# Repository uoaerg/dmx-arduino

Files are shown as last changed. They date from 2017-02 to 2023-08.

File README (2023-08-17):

This repository contains the full source code and hardware designs for the
Arduino shield used for teaching DMX at the University of Aberdeen. The Arduino
Mega 2560 compatible shield allows an Ardunio to operate as either a DMX bus
master or slave.

The dmx-arduino Board (Rev I and II) was designed by Cyril Danilesvski in 2014.
The software was written and was updated by Tom Jones, 2015-2017.
The software is updated by Gorry Fairhurst, 2020-2023.

# Uploading the code

Open the Arduino project from dmxcontroller/dmxcontroller.ino.

Import the libraries from the libraries/ into the Arduino IDE. It is
important that you do not allow the Aruduino IDE to update these libraries.

Compile and upload.

# Operation

Program mode and DMX addressing are controlled by the 12 dip switches on the
main sheild PCB. Program status is indicated using the three LEDs in most
program modes or using additional LEDs on the DE9 connector in other modes.

There is a default program that can is used in any empty slot in the program
mode. This program will only blink the green LED.

The RED LED on the board provides the DMX status. If valid DMX data has been seen
on the bus, then DMXTIMEOUT will flash the red LED. If no valid DMX data has
been seen for 1 sec this LED will be lit solidly. This functionality operates 
outside the control of any of the programs.

When the main loop of the program detects a change in program mode the green
LED will be flashed momentarily. This flash can be difficult to see when
turning off DIP switches, but is easier to see when turning on DIP switches.

## DIP Switches

The 12 DIP switches form a 12-bit number with the MSB starting with switch 1.
The program mode is encoded in the top three bits of the DIP switches and the
DMX address is encoded in the bottom 9 bits.

                  1 1 1
1 2 3 4 5 6 7 8 9 0 1 2
P P P D D D D D D D D D

The software has 8 modes (3 bits):

0 - DMX Controller
1 - Digital Output Control
2 - PWM Control 
3 - Servo Control
4 - Neopixel Strip Control
5 - Stepper Motor Control
6 - Unused.
7 - Long Strip Control

0 - DMX Controller Mode
	The programmed DMX address will be displayed on the 8 DE2PINs with the 9th
	bit displayed on the green LED.

	If a DMX address of 0 is selected on the DIP switches, the slot sequence
	0x55 0xFF 0x0F 0xF0 will be output for the first four DMX slots.

	In controller mode, the program will read from a 10K pot connected to POT_PIN. The
	10bit value from the ADC will be scaled (divided by 4) to fit with in a DMX
	byte. If this value is greater than 128, then the yellow LED will be lit. The
	scaled value from the pot. will be written to the DMX bus at the slot set by the DMX
	address.

1 - Digital control
	Eight DMX channels will be read from the bus. If the DMX value is
	greater than 128, then the corresponding DE2PIN will set high.

	The yellow LED shows the status of channel 1.

2 - PWM Control 
	The first eight DMX channels will be read from the bus. The corresponding
	DE2PINs will be given a PWM values from the DMX value.

	The yellow LED shows the status of channel 1.

3 - Servo Control
	The servo will be driven to a position based upon the DMX value at the selected
	DMX address.

	The yellow LED shows the status of channel 1.

4 - Neopixel Control
	An encoded colour value will be read from a set of DMX slots. Each *byte*
	encodes an RGB value. These values are split out then set to an attached
	LED strip using the Neopixel Library. These are sent as a time division
	multiplex as 3 serialised 8-bit colour values using the assigned pin.

	The yellow LED shows the status of channel 1.

5 - Stepper Motor Control
	An encoded stepper motor control value will be read from a set of DMX slots. 
	A set of 2 slots control the speed of rotation of the stepper motor and direction.
	A set of 2 slots sets an index position, and then controls the relative angle to 
	the indexed position. The rotation controls also control the speed of movement.

7 - Long Neopixel Control
	As mode 5, but with the timing adjusted to allow a long strip to be driven.

	The yellow LED shows the status of channel 1.

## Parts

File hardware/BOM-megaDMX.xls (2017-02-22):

Id | Designator | Description | Quantity | Designation | Supplier | Reference | Unit Price
1 | R2,R1 | Opto-couplers resistors | 2 | 330 | CPC | 2329531 | £0.004
2 | SHIELD1 | Arduino Mega shield | 1 | ARDUINO_MEGA_SHIELD | Pcb-Train |  | £6.34
3 | IC1 | Line Driver | 1 | 75176 | CPC | SC08420 | £0.20
4 | U1,U2,U3 | Opto-couplers | 3 | 6N137 | CPC | SC08395 | £0.85 | RS STOCK
5 | C1,C4,C2,C5,C3 | Integrated Circuits capacitors | 5 | 100nF | CPC | CA06294
6 | R10,R8 | DMX-RDM resistors | 2 | 562 | CPC | 1563234 | £0.004
7 | R9 | DMX-RDM resistors | 1 | 133 | Farnell | 9464417 | £0.004
8 | R6,R4,R5,R3 | Opto-couplers resistors | 4 | 470 | Farnell | 2329531 | £0.004
9 | J1 | DE9MD | 1 | J1 | CPC | 1260035 | £0.29
10 | K1 | 3 pin terminal block for XLR | 1 | XLR3 | CPC | 2008016 | £0.88
11 | IC2 | 5v DC-DC converter | 1 | NME5050SC | CPC | 1021456 | £3.41
12 | L1 | DC-DC inductor | 1 | 47uH | CPC | 2062675 | £0.24
13 | U4 | Octal buffer | 1 | 74HTC240 | CPC | SC09024 | £0.13 | RS STOCK
15 | C6 | DC-DC capacitor - CAP, ALU ELEC, 4.7UF | 1 | 47uF | CPC | 1236689 | £0.06
16 | C7 | C1 | 1 | 10nF | CPC | 2309024 | £0.02
17 | R11,R12,R13 | LED resistor | 3 | 220 | CPC | 2329500 | £0.01
18 | D2 | LED 3MM | 1 | LED | CPC | 2112096 | £0.12
19 | D3 | LED 3MM | 1 | LED | CPC | 2112104 | £0.12
20 | D4 | LED 3MM | 1 | LED | CPC | 2112106 | £0.12
21 | P1,P2,P3,P4 | Headers: serial & scope | 1 | RX_JMP,TX_JMP,RX,TX | CPC | 5217805 | £3.09
22 | SW1 | DIP switches 12 | 1 | DIPS | CPC | 1530701 | £1.42
24 | n/a | Double row long legged headers | 2 | Pin 22 through 53 | CPC | 1769164 | £2.70 | NO STOCK
25 | n/a | Stackable header kit | 1 | All other pins | CPC | SC12964 | £1.59
26 | n/a | LCD display | 1 |  | CPC | SC12121 | £4.28
27 | n/a | Arduino Mega | 1 |  | CPC | 1848688 | £15.00
28 | n/a | DIP SOCKET 20 | 1 |  | Farnell | 1183577 | £0.12
 |  |  |  |  | No arduino Total |  | £25.99
 |  |  |  |  |  | TOTAL | £40.99

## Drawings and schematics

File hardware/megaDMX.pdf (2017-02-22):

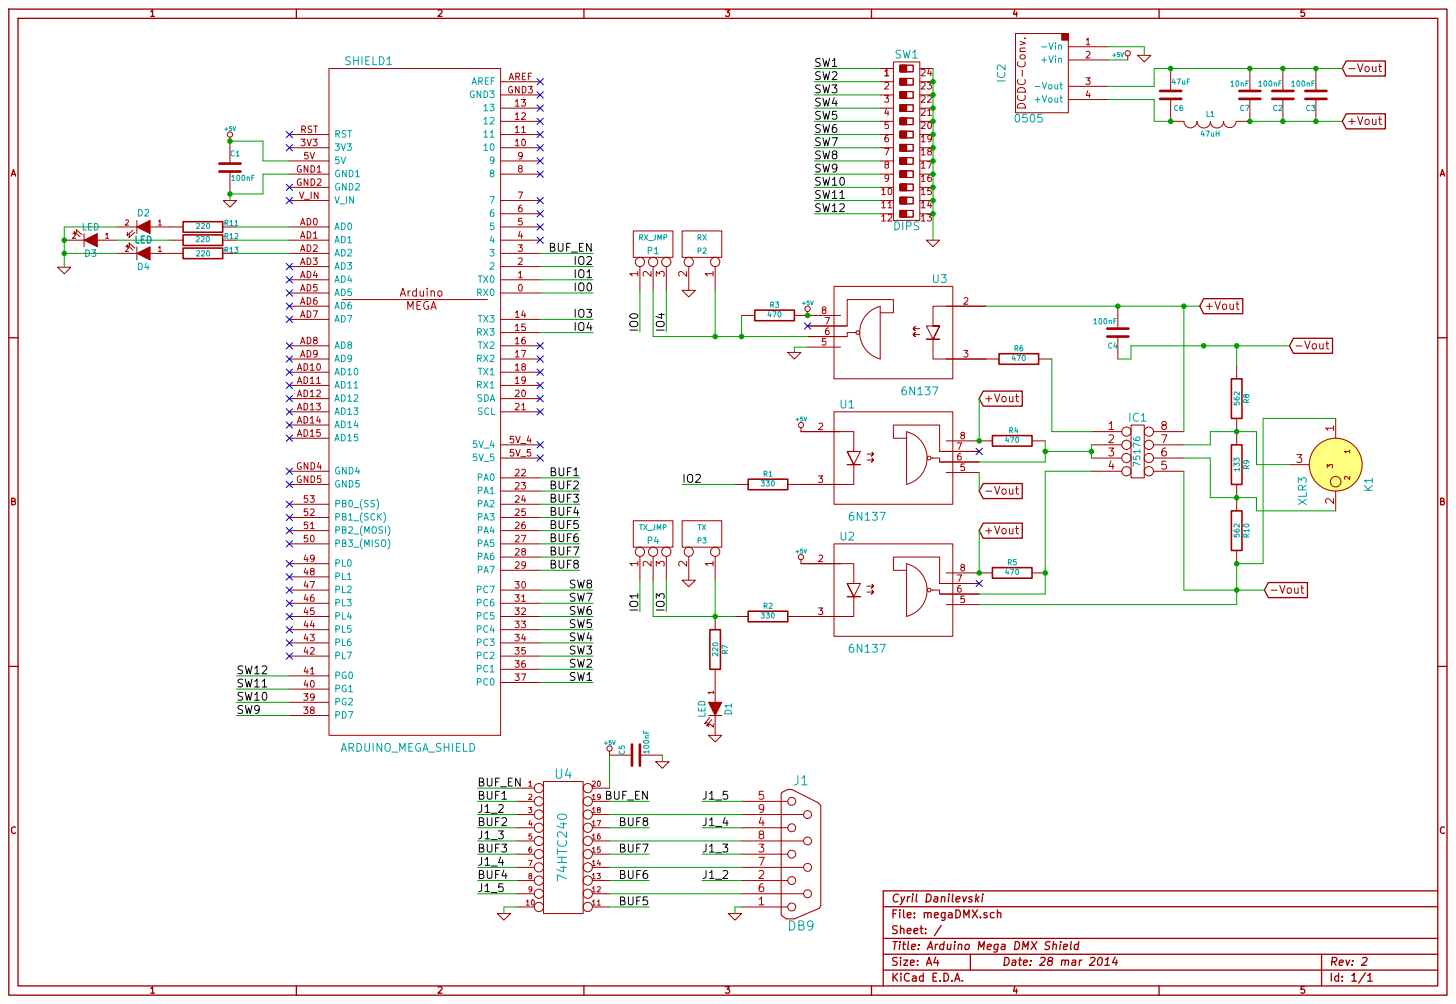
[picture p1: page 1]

File: megaDMX.sch
Sheet: /
Title: Arduino Mega DMX Shield

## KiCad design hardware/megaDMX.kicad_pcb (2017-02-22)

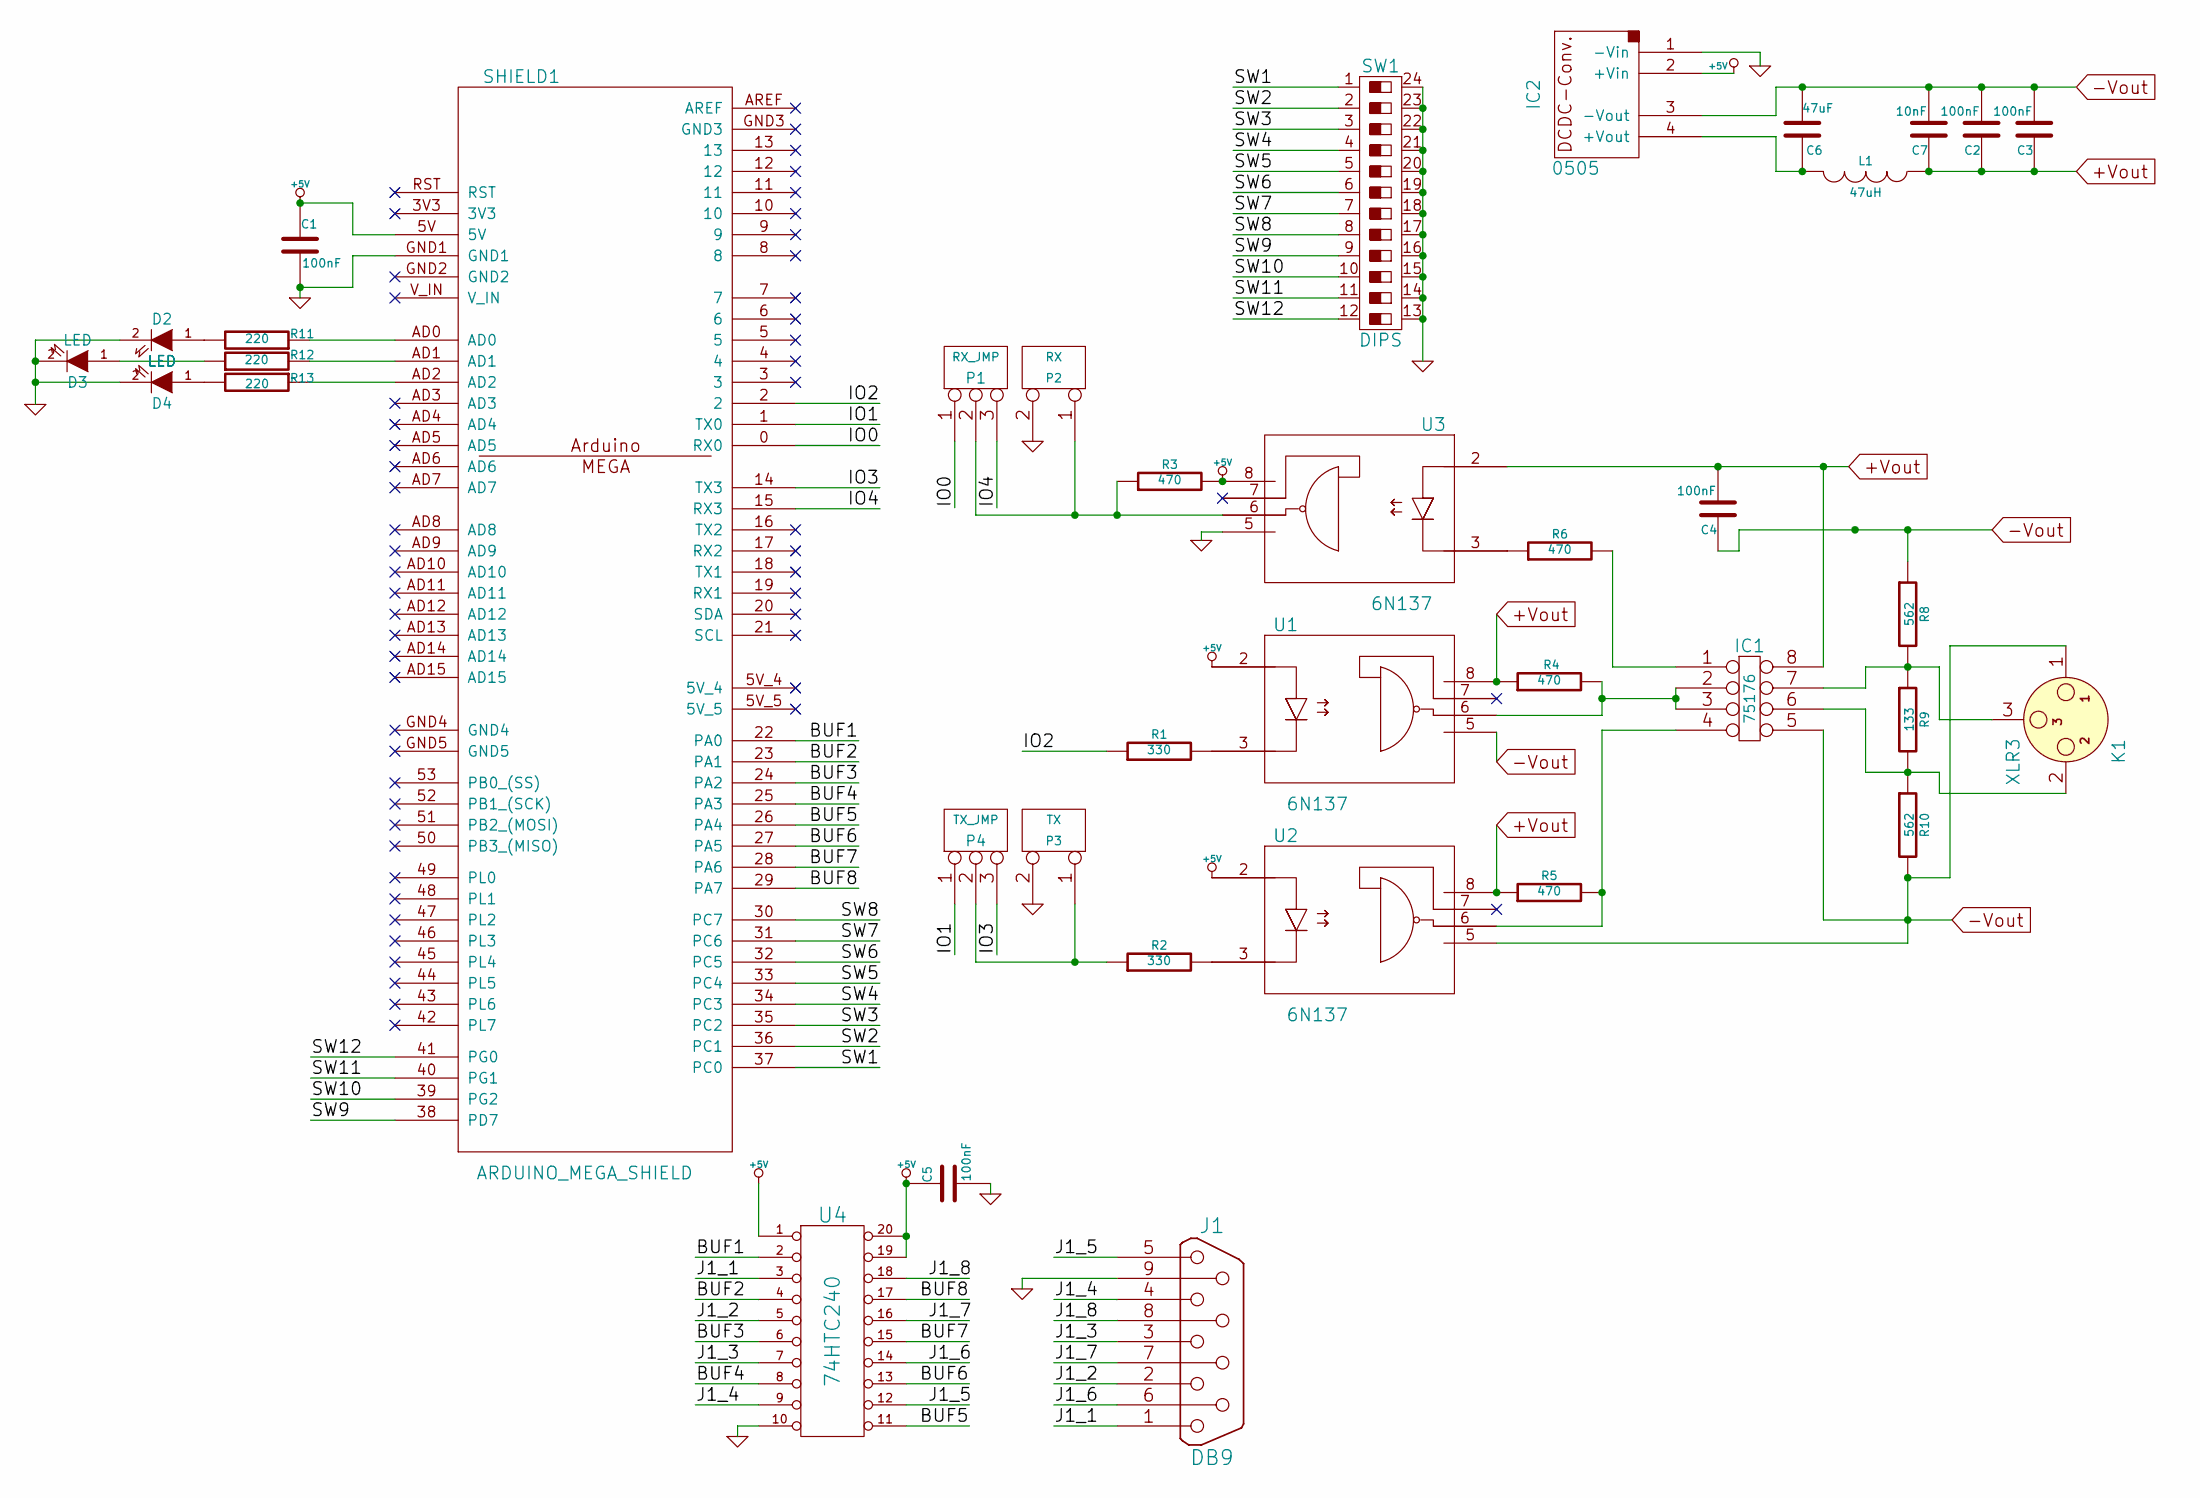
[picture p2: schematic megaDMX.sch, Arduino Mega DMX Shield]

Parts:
C1, C2, C3, C4, C5: 100nF
C6: 47uF
C7: 10nF
D2, D3, D4: LED
IC1: 75176
IC2: 0505
J1: DB9
K1: XLR3
L1: 47uH
P1: RX_JMP
P2: RX
P3: TX
P4: TX_JMP
R1, R2: 330
R3, R4, R5, R6: 470
R8, R10: 562
R9: 133
R11, R12, R13: 220
SHIELD1: ARDUINO_MEGA_SHIELD
SW1: DIPS
U1, U2, U3: 6N137
U4: 74HTC240

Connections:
+5V: C1.1, C5.1, IC2.2 (+Vin), R3.2, SHIELD1.5V, U1.2, U2.2, U3.8, U4.1, U4.19, U4.20
+Vout: C2.1, C3.1, C4.2, C7.1, IC1.8, L1.1, R4.1, R5.1, U1.8, U2.8, U3.2
-Vout: C2.2, C3.2, C4.1, C6.2, C7.2, IC1.5, IC2.3 (-Vout), K1.1, R8.1, R10.2, U1.5, U2.5
/BUF1: SHIELD1.22 (PA0), U4.2
/BUF2: SHIELD1.23 (PA1), U4.4
/BUF3: SHIELD1.24 (PA2), U4.6
/BUF4: SHIELD1.25 (PA3), U4.8
/BUF5: SHIELD1.26 (PA4), U4.11
/BUF6: SHIELD1.27 (PA5), U4.13
/BUF7: SHIELD1.28 (PA6), U4.15
/BUF8: SHIELD1.29 (PA7), U4.17
/IO0: P1.1, SHIELD1.0 (RX0)
/IO1: P4.1, SHIELD1.1 (TX0)
/IO2: R1.1, SHIELD1.2
/IO3: P4.3, SHIELD1.14 (TX3)
/IO4: P1.3, SHIELD1.15 (RX3)
/J1_1: J1.1, U4.3
/J1_2: J1.2, U4.5
/J1_3: J1.3, U4.7
/J1_4: J1.4, U4.9
/J1_5: J1.5, U4.12
/J1_6: J1.6, U4.14
/J1_7: J1.7, U4.16
/J1_8: J1.8, U4.18
/SW1: SHIELD1.37 (PC0), SW1.1
/SW2: SHIELD1.36 (PC1), SW1.2
/SW3: SHIELD1.35 (PC2), SW1.3
/SW4: SHIELD1.34 (PC3), SW1.4
/SW5: SHIELD1.33 (PC4), SW1.5
/SW6: SHIELD1.32 (PC5), SW1.6
/SW7: SHIELD1.31 (PC6), SW1.7
/SW8: SHIELD1.30 (PC7), SW1.8
/SW9: SHIELD1.38 (PD7), SW1.9
/SW10: SHIELD1.39 (PG2), SW1.10
/SW11: SHIELD1.40 (PG1), SW1.11
/SW12: SHIELD1.41 (PG0), SW1.12
GND: C1.2, C5.2, D2.2 (K), D3.2 (K), D4.2 (K), IC2.1 (-Vin), J1.9, P2.2 (PM), P3.2 (PM), SHIELD1.GND1, SW1.13, SW1.14, SW1.15, SW1.16, SW1.17, SW1.18, SW1.19, SW1.20, SW1.21, SW1.22, SW1.23, SW1.24, U3.5, U4.10
unnamed: R11.1, SHIELD1.AD0
unnamed: D2.1 (A), R11.2
unnamed: D4.1 (A), R13.2
unnamed: D3.1 (A), R12.1
unnamed: R12.2, SHIELD1.AD1
unnamed: R13.1, SHIELD1.AD2
unnamed: C6.1, IC2.4 (+Vout), L1.2
unnamed: P3.1, P4.2 (PM), R2.1
unnamed: P1.2 (PM), P2.1, R3.1, U3.6
unnamed: IC1.1, R6.2
unnamed: IC1.2, IC1.3, R4.2, U1.6
unnamed: IC1.6, K1.2, R9.2, R10.1
unnamed: IC1.7, K1.3, R8.2, R9.1
unnamed: R6.1, U3.3
unnamed: IC1.4, R5.2, U2.6
unnamed: R2.2, U2.3
unnamed: R1.2, U1.3

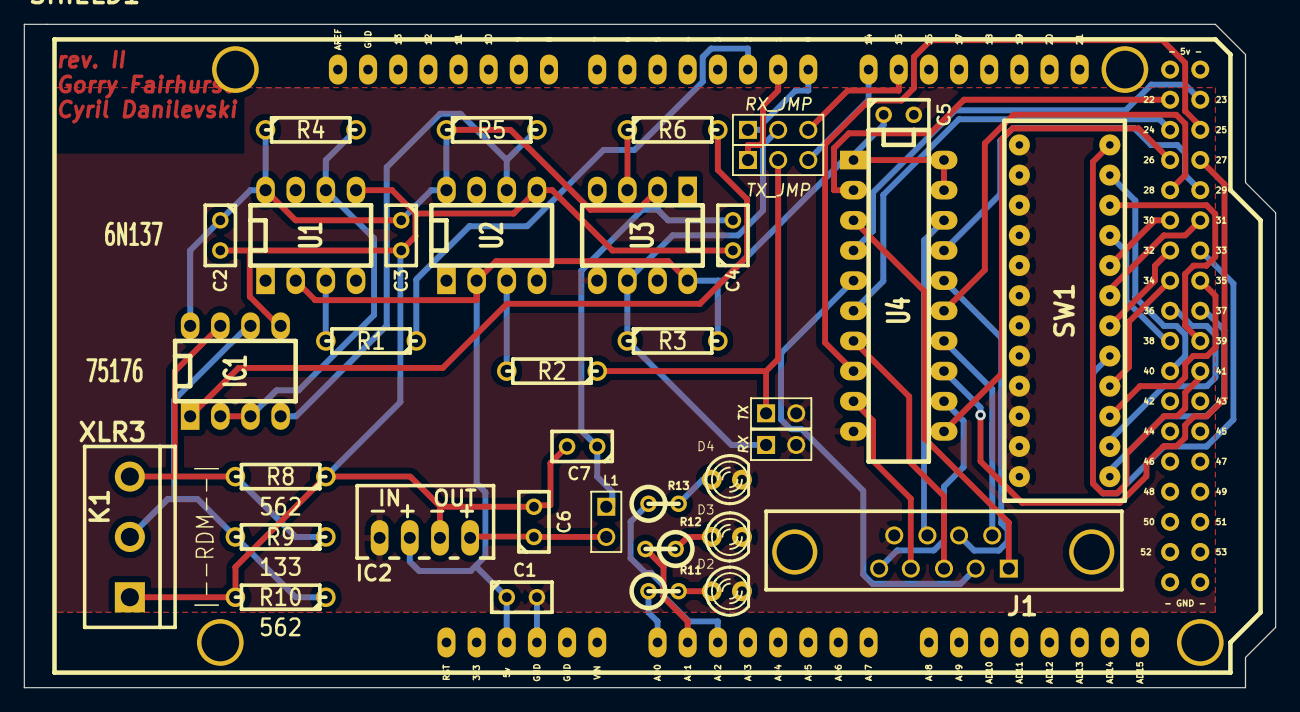
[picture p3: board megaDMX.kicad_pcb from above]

Board: 2 copper layers, 105.4 x 55.9 mm, 37 parts (0 on the bottom side), 54 nets.

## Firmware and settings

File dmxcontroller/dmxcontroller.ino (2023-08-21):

#include <DMXSerial.h>

/* dmx controller */
/*
 * Copyright (c) 2017 Tom Jones, UoA tom@erg.abdn.ac.uk
 * Copyright (c) 2023 Gorry Fairhurst, UoA gorry@erg.abdn.ac.uk
 * All rights reserved.
 *
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
 */

/* Rewrite completed by Aug 2023 */


/* NOTE USE INCLUDED LIBRARYIES ONLY,
A SERIAL CONFLICT exists in the on-line library,
https://github.com/mathertel/DMXSerial/tree/master
The Arduino MEGA 2560 boards use the serial port 0 on pins 0 an 1.
The vector numbers differ because you use the Mega board and not the UNO.
On Mega you have the option to use the port 1 for DMX and the Serial for printing to the Monitor.
see https://github.com/mathertel/DMXSerial/blob/master/src/DMXSerial_avr.h 
for details to enable DMX_USE_PORT1 and change your wiring.
The hack here is to reload DMX after each pixel load.
Aug 2023 GF */

#include <DMXSerial.h>
#include <Servo.h>

#include <Adafruit_NeoPixel.h>

extern "C" {
  #include "dmxboard.h"
  #include "pins.h"
  #include "dip.h"
}

#define DMXADDRESSMAX 513   /* maximum number of channels read in a frame */

/* Libary does not eturn DMXTIMEOUT correctly */
#define DMXTIMEOUT 1000   /* One Second timeout to take receiver off-line */

void controllermain(void);
void digitalmain(void);
void pwmmain(void);
void servomain(void);
void neopixelmain(void);
void steppermain(void);
void defaultprogram(void);
void neopixellong(void);
void printdipmode(void);

void readDMXChannels(int *, uint16_t );
void readStartDMXChannels(int *, uint16_t, uint16_t startaddr );

void stepmotor(int *motorpins, int *motorsteps, int direction, int step);
void stopmotor(int *motorpins);

int OutputDisabled;   /* Disable output signal */
uint8_t readRed(uint8_t);
uint8_t readGreen(uint8_t);
uint8_t readBlue(uint8_t);

void (*program)(void);
Servo servos[SERVOPINS_MAX];
int16_t indexposition = 0;

/* Driver for the WS2812 3-colour LED strip */
/* each pixel is programmed in a chain with 3x 8-bit colour values */
Adafruit_NeoPixel strip = Adafruit_NeoPixel
(
  LONGLEDCOUNT,   /* Maximum number of LEDs on the strip - use the longest size */
  STRIP_PIN,    /* Arduino output pin used for control */
  NEO_GRB + NEO_KHZ800  /* Colour Byte order and Strip Speed */
);

/* This is the menu for the switch configuration */
#define NUMPROGRAMS 8
void (*programs[NUMPROGRAMS])(void) = {
  controllermain,   /* Mode 0 */
  digitalmain,  /* Mode 1 */
  pwmmain,  /* Mode 2 */
  servomain,  /* Mode 3 */
  neopixelmain, /* Mode 4 */
  steppermain,  /* Mode 5 */
  defaultprogram, /* Mode 6 */
  neopixellong, /* Mode 7 */
};

/* This is the menu as a list of programs */
/* Note lsb and msb versions of the mode are provided in the comments ! */
char *program_name[]= {
  "DMX Controller ",  /* Mode 0  000 msb: 000 */
  "Digital Control",  /* Mode 1  001 msb: 100 */
  "PWM Control    ",  /* Mode 2  010 msb: 010*/
  "Servo Control  ",  /* Mode 3  011 msb: 110 */
  "Pixel Control  ",  /* Mode 4  100 msb: 001 */
  "Stepper Control",  /* Mode 5  101 msb: 101*/
  " --- None ---  ",  /* Mode 6  110 msb: 011 */
  "Long Pixel Cont.", /* Mode 7  111 msb: 111 */
};

/* -------------------------------------------------------------------------- */


void setup(void)
{

  /* Configure pins */
  pinMode(GREEN_LED, OUTPUT);
  pinMode(YELLOW_LED, OUTPUT);

  /* RED status LED on board
   * RED On indicates no DMX data; RED flashing indicates good DMX frames received. */
  pinMode(RED_LED, OUTPUT);

  pinMode(STRIP_PIN, OUTPUT);

  pinMode(POT_PIN, INPUT);
  pinMode(POT_PIN2, INPUT); // GF
  pinMode(POT_PIN3, INPUT); // GF
  pinMode(POT_PIN4, INPUT); // Gf
  pinMode(SENS_PIN5, INPUT); // GF - sensor input

  /* DIP switch input of address and mode */
  for(int i = 0; i < DIPMAX; i++) {
    pinMode(dipSwitches[i], INPUT);
    digitalWrite(dipSwitches[i], HIGH);
  }

  /* Line driver has two halves, pins are pulled high with a LOW */
  digitalWrite(DEENABLE1, LOW);
  digitalWrite(DEENABLE2, LOW);

  for(int i = 0;i < DEPINS_MAX; i++) {
    pinMode(depins[i],OUTPUT);
    digitalWrite(depins[i], HIGH);
  }
  for(int i = 0;i < PWMPINS_MAX; i++) {
    pinMode(pwmpins[i], OUTPUT);
  }
  for(int i = 0;i < SERVOPINS_MAX; i++) {
    pinMode(servopins[i], OUTPUT);
  }
  for(int i = 0;i < STEPPERPINS_MAX; i++) {
    pinMode(stepperpins[i], OUTPUT);
  }

  Serial.begin(9600);

  Serial.println("");
  Serial.println("---------------------------------------------------------");
  Serial.println("Build name:  " GIT);
  Serial.println("Board rev :  " DMXBOARDREV);
  
  Serial.print("Servo pins: {" );
    Serial.print(SERVO1PIN);
    Serial.print(",");
    Serial.print(SERVO2PIN);
  Serial.print("}, Pot pins: {");
  Serial.print( POT_PIN );
    Serial.print(",");
    Serial.print(POT_PIN2);
    Serial.print("}, PWM pins: {" );
    Serial.print( PWM1PIN );
    Serial.print(",");
    Serial.print( PWM2PIN ); 
    Serial.println("}");

#ifdef NEOPIXELDISPLAY
  /* Test routine for NEOPIXEL strip when enabled */
  Serial.print(LONGLEDCOUNT);
  Serial.print(" NeoPixels enabled, using pin: ");
  Serial.print(STRIP_PIN);

  strip.begin();  /* Initialize the WS2812 LED strip */
  strip.show();   /* Set all pixels in strip to 'off' */

  // Panel test executes for address > 502
  if (dipReadAddress() > 502) {
    Serial.print(" Running Neopixel test for ");
    Serial.print(LONGLEDCOUNT);
    Serial.println (" pixels.");
    strip.setPixelColor(0, strip.Color(255,255,255));
    for(int i = 1; i < LONGLEDCOUNT; i++) {
      strip.setPixelColor(i,
        strip.Color(
          random(5,255),
          random(5,255),
          random(5,255)
        )
      );
      strip.show();
      delay(100);
    }
  } else {
    Serial.println(" (Output test enabled when address > 502 )");
  }

  // Anyway clear the strip (there might be previosu garbage displayed)
  for(int i = 0; i < LONGLEDCOUNT; i++)
    strip.setPixelColor(i, strip.Color(0, 0, 0) );
  strip.show();
  
#endif //NEOPIXELDISPLAY
  printdipmode();

  Serial.println("---------------------------------------------------------");

  DMXSerial.init(DMXReceiver);  /* initialise the DMX receive code */

  strip.begin();  /* Initialize the WS2812 LED strip */
  strip.show();   /* Set all pixels in strip to 'off' */
}

void 
loop()
{
  static int led = 0;              /* for red LED */
  static int lastflash = millis(); /* for red LED */

  dmxAddress = dipReadAddress();
  dmxMode = dipReadMode();

  if(dmxMode >= 0 && dmxMode < NUMPROGRAMS) {
    void (*newprogram)(void) = programs[dmxMode];

    if(newprogram != program) {   /* If the program changed */

      printdipmode();

      digitalWrite(GREEN_LED, HIGH);  /* Green board status LED */
      digitalWrite(YELLOW_LED, LOW);  /* Yellow board status LED */

      /* Pull the line drivers low, which is logical HIGH */  
      for(int i = 0;i < DEPINS_MAX; i++)
        digitalWrite(depins[i], HIGH);

      /* Detach any attached servos when changing from servomain */
      if(program == servomain && newprogram != servomain) 
        for(int i = 0;i < SERVOPINS_MAX; i++) 
          if(servos[i].attached())
            servos[i].detach();

      /* If we have started the control program, enable DMX control */
      /* This sets the line driver to transmit and starts sending */
      if(newprogram == controllermain) {
        DMXSerial.init(DMXController);
        /* 0 each slot to make DMXSerial always send a full frame */
        for (int i = 0; i < 512; i++)
          DMXSerial.write(i+1, 0x00);
      } else if(program == controllermain) {
        DMXSerial.init(DMXReceiver);
      }

      program = newprogram;

      /* Add some delay when we change programs */
      delay(200);
      digitalWrite(GREEN_LED, LOW);
    }
  }

  /* Call main function */
  if(program != NULL)
    program();

  /* Clear the red status LED if in controller mode
   * otherwise the blink the red status LED when there is DMX data within our timeout.
   * If no data, set the status red LED high, this is how commercial hardware works.
   */
  if(program == controllermain) {
    digitalWrite(RED_LED, LOW);
  } else {
    if(DMXSerial.noDataSince() < DMXTIMEOUT) {
      // Serial.println(DMXSerial.noDataSince()); // Enbale to trace idle time
      OutputDisabled = false;
      digitalWrite(RED_LED, led);
      int now = millis();
      if ( now - lastflash > 200) {
        led = !led;
        lastflash = now;
      }
    } else {
      /* Outputs ought to be disabled here */
      /* Currently no action taken */
      digitalWrite(RED_LED, HIGH);
      OutputDisabled = true;
    }
  }
}

/* Read and print DMX address and mode from the DIP switches */
void printdipmode()
{
  int address;
  int mode;

  address = dipReadAddress();
  Serial.print("DMX Address: ");
    Serial.print(address, DEC);
    Serial.print(" (b");
    Serial.print(address, BIN);

  Serial.print(") ");

  mode = dipReadMode();
  Serial.print("Board mode: ");
  Serial.print(mode, DEC);
  Serial.print(" (b");
  Serial.print(mode, BIN);
  Serial.print(") ");
  Serial.println( program_name[mode] );
}

/* ************************************************* */
/* Program to execute when no valid mode is selected :
 * The green LED flashes */

void
defaultprogram()
{
  static int led = 0;
  static unsigned long lasttoggle = micros();
  unsigned long now = millis();

  if (now - lasttoggle > 200) {
    led = !led;
    lasttoggle = now;
  }
  // Try setting each output pin for testing
  // digitalWrite(SERVOPIN1, led);
    // digitalWrite(SERVOPIN2, led);
  // digitalWrite(PWM1PIN,led);
    // digitalWrite(PWM2PIN, led);
  digitalWrite(GREEN_LED, led); 
  digitalWrite(YELLOW_LED, !led);
}

/* ************************************************* */
/* Program to execute in controller mode             */
/* Outputs low order DIP switches output to D9 socket*/
/* Control waveform sent on DMX output               */
/* 1. frame is static if low order DIP switch is 0   */
/* 2. frame sets slot for switch with value from pot */
/* Yellow LED indicates if pot > 128                 */

void 
controllermain()
{
  uint16_t value = 1;
  uint8_t reading = 0;

  static int lastAddress;

  /*  RED LED is set off in main, because no DMX Input in this mode */

  /* If the address has changed, then clear slots at the last address */
  if(dmxAddress != lastAddress) {
    if(lastAddress == 0x00) {
      /* Overwrite the static frame contents when address was previously zero */
      DMXSerial.write(1, 0x00);
      DMXSerial.write(2, 0x00);
      DMXSerial.write(3, 0x00);
      DMXSerial.write(4, 0x00);
    } else {
      /* Reset last slot at last addresss to zero */
      DMXSerial.write(lastAddress, 0x00);
    }
  }
  /* Read the pot value and set the yellow status LED only when > 128 */
  reading = (uint16_t)analogRead(POT_PIN) / 4; 
  if(reading > 127)
    digitalWrite(YELLOW_LED, HIGH);
  else
    digitalWrite(YELLOW_LED, LOW);

  /* If address is zero, send a recognisable pattern of 4 slots & set green LED off */
    /* Else if not zero, set the slot value at the slected address & set green LED on */
  if(dmxAddress == 0) {
    DMXSerial.write(1, 0x55); /* Slot 1 */
    DMXSerial.write(2, 0xFF); /* Slot 2 */
    DMXSerial.write(3, 0x0F); /* Slot 3 */
    DMXSerial.write(4, 0xF0); /* Slot 4 */
    digitalWrite(GREEN_LED, LOW);
  } else {
    DMXSerial.write(dmxAddress, reading);
    digitalWrite(GREEN_LED, HIGH);
  }
  lastAddress = dmxAddress;

  /* For debugging set the output port */
  /* Output a copy of the DIP switch pattern on the output ports */
  for(int i = 0;i < DEPINS_MAX; i++) {
    int status = !(dmxAddress & value);
    digitalWrite(depins[i], status);  
    value = value << 1;
  }

  /* For debugging set the green LED from the last bit of address */
  // value = digitalRead(DIP9) << 8;
  // if(value > 0)
  //  digitalWrite(GREEN_LED, HIGH);  
  //else
  //  digitalWrite(GREEN_LED, LOW); 
}

/* ************************************************* */
/* Program to execute when digital mode selected     */
/* Reads 8 channels of the DMX frame                 */
/* outputs a logic 1 on main port when channel > 128 */
/* Yellow LED indicates value of channel 1           */
void 
digitalmain()
{
  int values[DEPINS_MAX];
  readDMXChannels(values,DEPINS_MAX);

  if(values[0] > 0)
    digitalWrite(YELLOW_LED, HIGH); 
  else
    digitalWrite(YELLOW_LED, LOW);  

  for(int i = 0;i < DEPINS_MAX; i++)
    if(values[i] > 128)
      digitalWrite(depins[i], DEHIGH);
    else
      digitalWrite(depins[i], DELOW);
}

/* ************************************************* */
/* Program to execute when PWM mode selected         */
/* Reads PWMPINS_MAX channels of the DMX frame       */
/* outputs PWM for channel value on analogue output  */
/* Yellow LED indicates if slot 1 > 127              */
/* Yellow LED indicates if slot 2 > 127              */

void 
pwmmain()
{
  int values[PWMPINS_MAX];

  readDMXChannels(values,PWMPINS_MAX);

  if(values[0] > 127)
    digitalWrite(YELLOW_LED, HIGH); 
  else
    digitalWrite(YELLOW_LED, LOW);

  if(values[1] > 127)
    digitalWrite(GREEN_LED, HIGH);  
  else
    digitalWrite(GREEN_LED, LOW); 
  
  for(int i = 0;i < PWMPINS_MAX; i++)
    analogWrite(pwmpins[i], values[i]);
}

/* ************************************************* */
/* Program to execute when servo mode selected       */
void 
servomain()
{
  int values[SERVOPINS_MAX];

  for(int i = 0;i < SERVOPINS_MAX; i++)
    if(!servos[i].attached())
      servos[i].attach(servopins[i]);

  readDMXChannels(values,SERVOPINS_MAX);

  if(values[0] > 0)
    digitalWrite(YELLOW_LED, HIGH); 
  else
    digitalWrite(YELLOW_LED, LOW);  

  for(int i = 0; i < SERVOPINS_MAX; i++) {
     /* Convert dmx value to degrees */
    int value = values[i]/255.0f * 180; 
    servos[i].write(value);
  }
}

/* ************************************************* */
/* Program to execute when WS2812 mode selected       */
/* outputs TDM waveform for each channel value onto a*/
/* serial WS2812 port, one channel per LED           */
/* channel value is mapped via a colour lookup table */
/* to three 8-bit colour values for each pixel       */
/* Yellow LED indicates if channel 1 > 128           */
void
neopixelmain()
{
  int values[LEDCOUNT];

  // GF: Awkwardly, the Neopixel library doesn't coexist with the DMX ISR
  // A solution calls DMXSerial.init(DMXReceiver) here each time!
  DMXSerial.init(DMXReceiver);

  // We might need a pause here .. for the initialisation and to grab a DMX frame //
  delay(75); // 100 ms ... depends on refersh rate

  readDMXChannels(values,LEDCOUNT); 
  if(values[0] > 127)
    digitalWrite(YELLOW_LED, HIGH); 
  else
    digitalWrite(YELLOW_LED, LOW);  

  for(int i = 0;i < LEDCOUNT; i++) {
    strip.setPixelColor(i,
      strip.Color(
        readRed(values[i]),
        readGreen(values[i]),
        readBlue(values[i])
      )
    );
  }
  strip.show();
}

/* ************************************************* */
/* neopixellong                                      */
/* Varient  to execute when WS2812 mode selected     */
/* outputs TDM waveform for each channel value onto a*/
/* serial WS2812 port, one channel per LED           */
/* channel value is mapped via a colour lookup table */
/* to three 8-bit colour values for each pixel       */
/* Yellow LED indicates if channel 1 > 128           */
void
neopixellong()
{
  int values[LONGLEDCOUNT];
  // GF: Awkwardly, the Neopixel library doesn't coexist with the DMX ISR
  // A solution calls DMXSerial.init(DMXReceiver) here each time!
  DMXSerial.init(DMXReceiver);
  // We might need a pause here .. for the initialisation and to grab a DMX frame //
  delay(75); // 100 ms ... depends on refersh rate

  readDMXChannels(values,LONGLEDCOUNT); 
  if(values[0] > 127)
    digitalWrite(YELLOW_LED, HIGH); 
  else
    digitalWrite(YELLOW_LED, LOW);  
 
  for(int i = 0;i < LONGLEDCOUNT; i++) {
    strip.setPixelColor(i,
      strip.Color(
        readRed(values[i]),
        readGreen(values[i]),
        readBlue(values[i])
      )
    );
  }
  strip.show();
}

/* ************************************************* *
 * steppermain                                       *
 * Main stepper motor function                       *
 *   The red status LED monitors DMX (flashes)       *
 *   The yellow status LED set when rotation enabled *
 *   The green status LED set when indexing is used  *
 *                                                   *
 * The stepper motor is controlled from 4 slots      *
 * Slot 1: Rotation speed, this rotates when > 0     *
 * Slot 2: Direction: forward <=128, reverse > 128   *
 * Slot 3: Index mode disabled = 0                   *
 *         Indexing enabled = 50-200                 *
 *         Set index reference = 255                 *
 * Slot 4: Set the index angle (0 to 360 degrees)    */

void
steppermain()
{
  uint16_t stepdelay = 25600;
  int clockwise = 1;
  int values[STEPPERCHANNELS];  /* Store values of all slots needed */
  int16_t stepperindex = 0; // Target stepper position 
  int local_use = false; // enable or disable the demo functions - note current hardware is rev-II
    uint16_t local_speed;
  uint16_t local_index;
  readDMXChannels(values, STEPPERCHANNELS);

  /*/ ----  This is onlky used with the demo unit
  /* Read the values from pots if needed */
  /* values are 0..255; fully rotated = off. */
  /* DMX needed to set an index. */
  if (local_use) {
    local_speed = (uint16_t)analogRead(POT_PIN2) / 2; 
    if (local_speed < 320) {
      /* Not fully turned, value will over-ride the speed from DMX */
      if (local_speed <= 255 ) {
        values[STEPPER_ROTATION_SPEED] = local_speed; 
      } else 
      {
        values[STEPPER_ROTATION_SPEED] = 255;
      }
      values[STEPPER_ROTATION_DIRECTION] = 127; /* Also enable rotation */
    }
   
    local_index = (uint16_t)analogRead(POT_PIN) / 2; 
    if (local_index < 320) {
      /* Will over-ride the speed from DMX */
      /* Note index needs to be set from DMX */
      if (local_index <= 255 ) {
        values[STEPPER_INDEX_ROTATION] = local_index; 
      } else 
      {
        values[STEPPER_INDEX_ROTATION]= 255;
      }
    }
 
  } 
  //---- Remainder is the normal stepper motor control
  

  /* Setup index referencing, or disable indexed use if requested. */
  /* Note: This happens even if the motor is not moving
  /* A slot value of 255 records a new index reference position */
  /* See if the indexing is being used (green LED on for indexed) */
  if (values[STEPPER_INDEX_MODE] < 50) {
    // Not in indexed mode
    digitalWrite(GREEN_LED, LOW);
  }
  else {
   // indexed mode
    digitalWrite(GREEN_LED, HIGH);
    if (values[STEPPER_INDEX_MODE] == 255) {
      // We are  at the reference position
      indexposition = values[STEPPER_INDEX_ROTATION] << 1; 
    }
  }

  /* If the motor is not allowed to rotate (yellow LED off) */
  if (values[STEPPER_ROTATION_SPEED] == 0 || values[STEPPER_ROTATION_DIRECTION] == 0) {
    stopmotor(stepperpins);
    digitalWrite(YELLOW_LED, LOW);
    return;
  }
  
  // Rotation was enabled, continue processing the stepper motor action ...
  /* Set yellow status LED on when rotation is enabled */
  digitalWrite(YELLOW_LED, HIGH);
  
  /* First see is indexing mode is enabled? */
  if (values[STEPPER_INDEX_MODE] < 50 ) {
    /* This stepper motor is not using indexing */
    /* Now rotate the stepper motor at the required speed */

    clockwise = values[STEPPER_ROTATION_DIRECTION] > 131 ? 1 : 0;
    stepdelay = ((255 - values[STEPPER_ROTATION_SPEED]) + 1)  * 128;

    /* TODO: missing direction-based step speed shift */
    stepmotor(stepperpins, motorsteps, clockwise, stepdelay);
  } else {
    /* Index mode is being used for this stepper motor */
    /* So, check if index movement is enabled, there are null values
     * 200...254 before the value that triggers indexing */
    if (values[STEPPER_INDEX_MODE] >= 200
        && values[STEPPER_INDEX_MODE] <= 254)
      return; //paused

    /* Now get the relative index to the reference, and see if we need to move */
    stepperindex = values[STEPPER_INDEX_ROTATION] << 1;

    /* Check if motor is already at the indexed position */
    if (indexposition == stepperindex) {
      /*
       * Leave the motor free when we reach the index. If there is a load
       * on the motor (something heavy that will turn it) you may want to
       * hold the motor at the index instead.
       * The green LED should already be on.
       */
      stopmotor(stepperpins);
      return;
    }

    /* Otherwise the motor now needs to move towards the required offset to the index */
    clockwise = indexposition > stepperindex? 0 : 1;
    stepdelay = ((255 - values[STEPPER_ROTATION_SPEED]) + 1)  * 128;
    stepmotor(stepperpins, motorsteps, clockwise, stepdelay);
  }
}

/* Function to move the stepper motor */
void
stepmotor(int *pins, int *steps, int direction, int stepdelay)
{
  static unsigned long laststep = micros();
  static int step = 0;
  unsigned long now = micros();

  stepdelay = max(stepdelay, 1100);

  if ((now - laststep) > stepdelay) {
    step += direction ?  1 : -1;

    if (step < 0) {
      step = 7;
      indexposition--;
    }
    if (step > 7) {
      step = 0;
      indexposition++;
    }
    if (indexposition < 0)
      indexposition == 511;
    if (indexposition > 511)
      indexposition == 0;

    digitalWrite(pins[0], steps[step] & MOTORPIN1_MASK);
    digitalWrite(pins[1], steps[step] & MOTORPIN2_MASK);
    digitalWrite(pins[2], steps[step] & MOTORPIN3_MASK);
    digitalWrite(pins[3], steps[step] & MOTORPIN4_MASK);

    laststep = now;
  }
}

/* Function to move the stepper motor */
void stopmotor(int *pins)
{
    digitalWrite(pins[0], LOW);
    digitalWrite(pins[1], LOW);
    digitalWrite(pins[2], LOW);
    digitalWrite(pins[3], LOW);
}
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

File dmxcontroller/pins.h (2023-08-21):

/*  Pins.h */
/*
 * Copyright (c) 2017 Tom Jones tom@erg.abdn.ac.uk
 * Copyright (c) 2023 Gorry Fairhurst gorry@erg.abdn.ac.uk

 * All rights reserved.
 *
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
 */

#ifndef PINS_H
#define PINS_H

#include "dmxboard.h"

/* Board status LEDs */
#define GREEN_LED  A0
#define YELLOW_LED A1
#define RED_LED    A2

/* Potentiometer input for input of slot value in controller mode */
/* Other pot/switches for specific builds */
#define POT_PIN    A3
#define POT_PIN2   A4
#define POT_PIN3   A5
#define POT_PIN4   A6
#define SENS_PIN5  A7 

#define NEOPIXELDISPLAY     /* Uncomment to enable NEOPIXEL display */
/* WS2812 TDM strip configuration */
#ifdef NEOPIXELDISPLAY
  // No of LEDs is a strip - Long strips have timing implications
  #define LEDCOUNT 16 
  #define LONGLEDCOUNT 128 
  // #define STRIP_PIN 22
  #define STRIP_PIN 9
#endif

#define TRIGGER_PIN 8

/* Pin to use for Servo output */
#define SERVOPIN 13

/* SERVO mode output configuration */
#define SERVOPINS_MAX 2
#define SERVO1PIN 12 
#define SERVO2PIN 13

static int servopins[SERVOPINS_MAX] =
{
	SERVO1PIN,
	SERVO2PIN
};

/* PWM mode output configuration */
#define PWMPINS_MAX 2
#define PWM1PIN 10
#define PWM2PIN 11

static int pwmpins[PWMPINS_MAX] =
{
	PWM1PIN,
	PWM2PIN
};


/* D 9 Output Socket on the mega shield */
#define DEPINS_MAX 8

#define DEENABLE1 3
#define DEENABLE2 4

#if REV == REV_II

	#define DE1PIN1 26
	#define DE1PIN2 24
	#define DE1PIN3 25
	#define DE1PIN4 23
	#define DE1PIN5 22
	#define DE1PIN6 27
	#define DE1PIN7 28
	#define DE1PIN8 29

	/* REV_II DEPINS are routed through an inverting buffer */
	#define DEHIGH LOW
	#define DELOW HIGH

#elif REV == REV_IIIA

	#define DE1PIN1 24
	#define DE1PIN2 22
	#define DE1PIN3 27
	#define DE1PIN4 30
	#define DE1PIN5 31
	#define DE1PIN6 26
	#define DE1PIN7 29
	#define DE1PIN8 28
	
	#define DEHIGH HIGH
	#define DELOW LOW

#endif

static int de1pins[DEPINS_MAX] = 
{
	DE1PIN1,
	DE1PIN2, 
	DE1PIN3, 
	DE1PIN4, 
	DE1PIN5, 
	DE1PIN6, 
	DE1PIN7, 
	DE1PIN8,
};

#define depins de1pins

/* DIP Switch mapping to I/O pins */
#define DIPMAX 12

#if REV == REV_II

	#define DIP1 37
	#define DIP2 36
	#define DIP3 35
	#define DIP4 34
	#define DIP5 33
	#define DIP6 32
	#define DIP7 31
	#define DIP8 30 
	#define DIP9 38
	#define DIP10 39 
	#define DIP11 40 
	#define DIP12 41

#elif REV == REV_IIIA

	#define DIP1 49
	#define DIP2 48
	#define DIP3 47
	#define DIP4 43
	#define DIP5 42
	#define DIP6 41
	#define DIP7 40
	#define DIP8 39
	#define DIP9 38
	#define DIP10 37
	#define DIP11 36
	#define DIP12 34

#else
	#error "please set board revision"
#endif // REV switch

static int dipSwitches[DIPMAX] = 
{
	DIP1, 
	DIP2, 
	DIP3, 
	DIP4, 
	DIP5, 
	DIP6, 
	DIP7, 
	DIP8, 
	DIP9, 
	DIP10, 
	DIP11, 
	DIP12 
};

#define STEPPERPIN1 50
#define STEPPERPIN2 51
#define STEPPERPIN3 52
#define STEPPERPIN4 53
#define STEPPERPINS_MAX 4

#define STEPPER_ROTATION_SPEED 0
#define STEPPER_ROTATION_DIRECTION 1
#define STEPPER_INDEX_MODE 2
#define STEPPER_INDEX_ROTATION 3


#define STEPPERCHANNELS 4

static int stepperpins[STEPPERPINS_MAX] =
{
	STEPPERPIN1,
	STEPPERPIN2,
	STEPPERPIN3,
	STEPPERPIN4
};

#define MOTORPIN1_MASK 0x01
#define MOTORPIN2_MASK 0x02
#define MOTORPIN3_MASK 0x04
#define MOTORPIN4_MASK 0x08

#define MAXSTEPS 8

static int motorsteps[MAXSTEPS] =
{
	B01000,
	B01100,
	B00100,
	B00110,
	B00010,
	B00011,
	B00001,
	B01001
};

/* Global mode variables read from DIP switches */
uint8_t dmxMode;
uint16_t dmxAddress;

#endif	//PINS_H

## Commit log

2017-02-22 Import of dmx-arduino from private svn
    [BOM-megaDMX.xls, megaDMX.kicad_pcb, megaDMX.sch]
2017-03-11 Disable scope debug in hte DMX Library
    Build fails with scope debug enabled, this feature from the original library has never worked for me. It is still worth trying to get this to work in the future. The frame trigger should be useful on low end scopes.
2018-02-23 print git rev on boot
2018-02-23 On mode change to testmode, write 0 for each slot value. This stops DMXSerial truncating the frame around slot 30
2018-12-04 Import definitions for rev 3 of the board
2019-02-22 correct logic for board revisions
2019-02-26 Remove debug print
2019-02-26 A first whack at a stepper mode
2019-05-16 Raise the minimum delay
    The motor can be eased into a higher rate than it can start at. Pin the
    maximum speed (higher minimum delay) to a level we can always start at.
2019-07-29 Final stepper support
2023-03-15 Comment about Neopixel timing
    Added note about long LED strips taking time to serialise the TDM output to the Neopixel;
2023-03-16 Fix Neopixel Panel addr >510
    Also re-initiallise DMX each loop;
    [dmxcontroller.ino]
2023-03-16 Number of Neopixel LEDs = 32
2023-08-16 Update dmxcontroller.ino
    Added support for long LED strips for address >=508
2023-08-16 Update dmxcontroller.ino
    Issue with DMX ports on Mega
    [dmxcontroller.ino]
2023-08-17 Update dmxcontroller.ino
    Added long LED mode
2023-08-18 Update dmxcontroller.ino
    Changes: This unmangles the logic in the stepper motor code and creates a long neoxpixel mode.
    Both need to be tested.
2023-08-18 Update dmxcontroller.ino
    Update with working stepper
2023-08-18 Update pins.h
    Updated LEDLENGTH here.
2023-08-18 Update dmxcontroller.ino
    Final version for flashing of boards Aug 2023
2023-08-20 Added more printing at start dmxcontroller.ino
2023-08-20 Added local support for stepper control dmxcontroller.ino
